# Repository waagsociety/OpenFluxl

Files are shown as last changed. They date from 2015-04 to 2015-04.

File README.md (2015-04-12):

# OpenFluxl
Open Source Digital Microfluidic Device

> This project is currently under development at Waag Society's Open Wetlab

# OpenFluxl v.0.1 Release Notes

# Circuit

The OpenFluxl Device needs to apply a voltage of approx. 300V to individual fluxls. In order to generate this potential from 12V a Boost Converter circuit is necessary.

The circuit is based on: http://reibot.org/2011/08/07/intro-to-boost-converter/

A TVS diode is added in the circuit over the main capacitor as an additional safety measure.

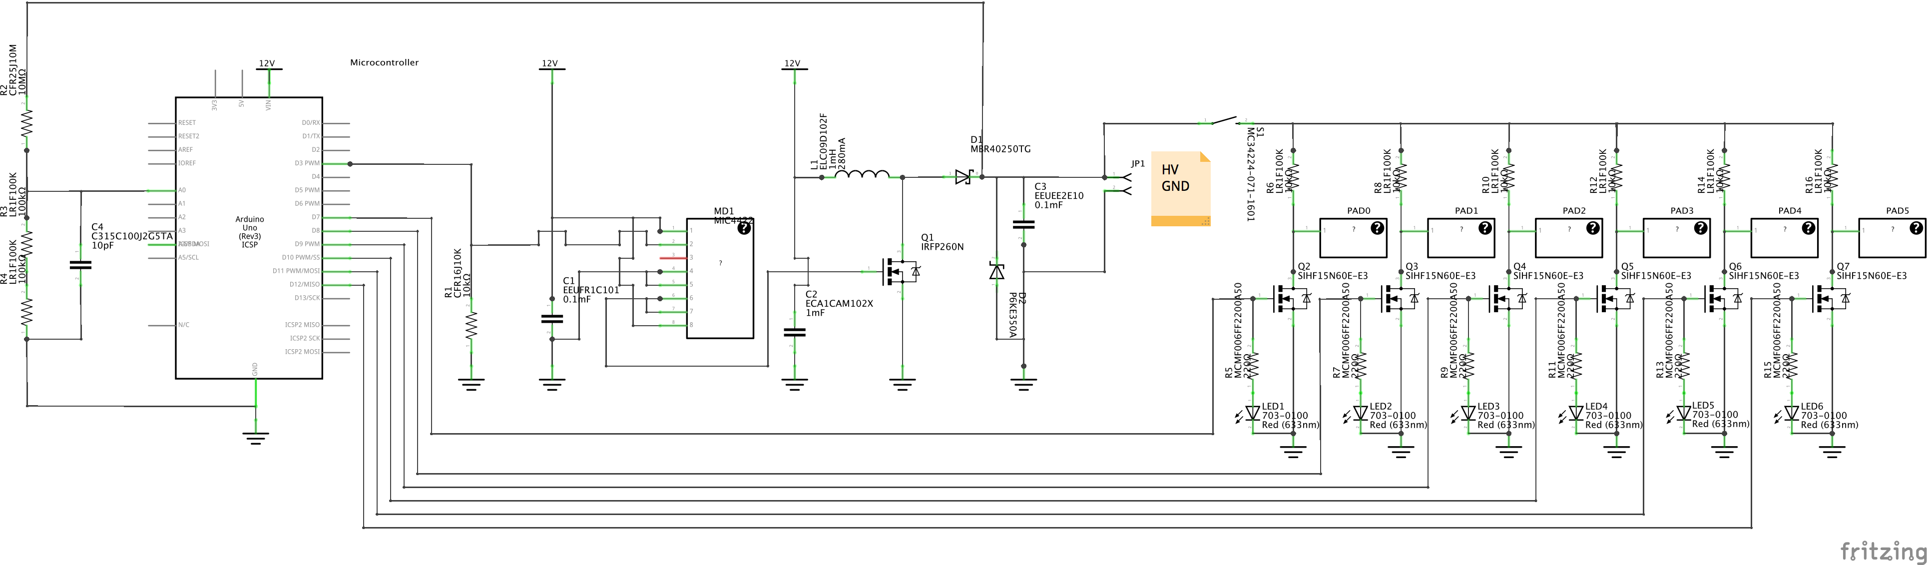
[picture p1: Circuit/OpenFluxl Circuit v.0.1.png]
Circuit Scheme


# Arduino Code

The Arduino code is based on: http://reibot.org/2011/08/07/intro-to-boost-converter/

# PCB

For initial testing the PCB of GuadiLabs OpenDrop is used: http://www.gaudi.ch/GaudiLabs/?attachment_id=440

# Components

Only through hole components have been used for breadboard prototyping.

The 1000V USB prototector is optional, for the brave.

# Pictures
Boost Converter:
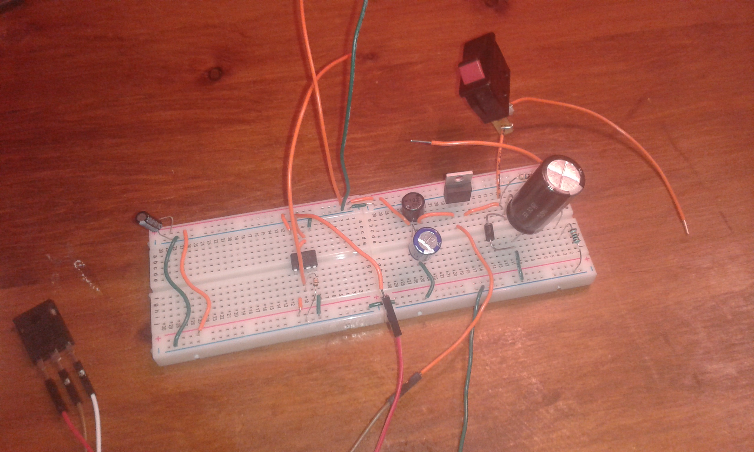
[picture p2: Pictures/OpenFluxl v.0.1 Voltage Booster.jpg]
Boost Converter


Fluxl Controller:
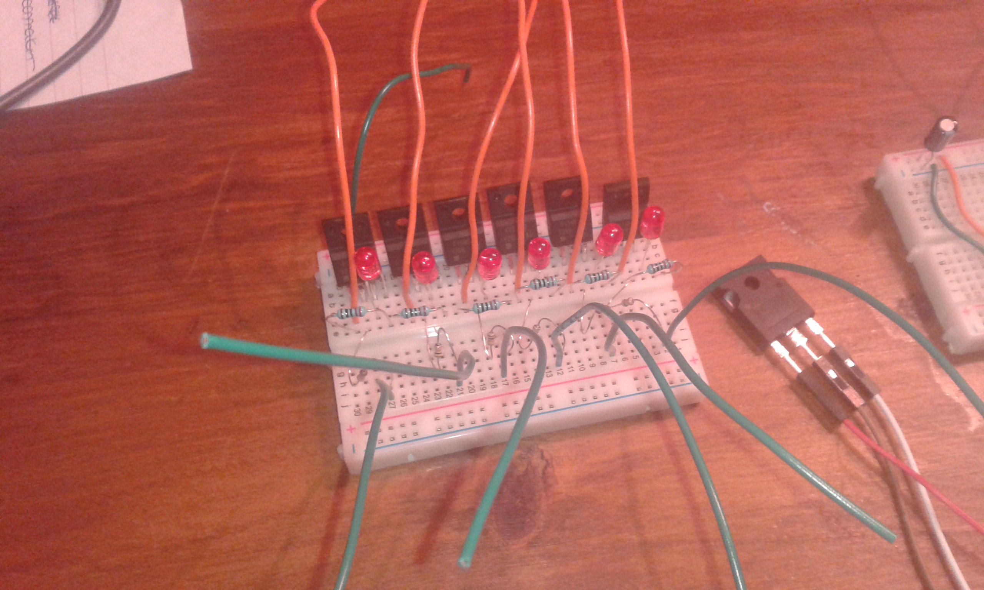
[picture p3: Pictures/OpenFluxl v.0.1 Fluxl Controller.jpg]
Fluxl Controller


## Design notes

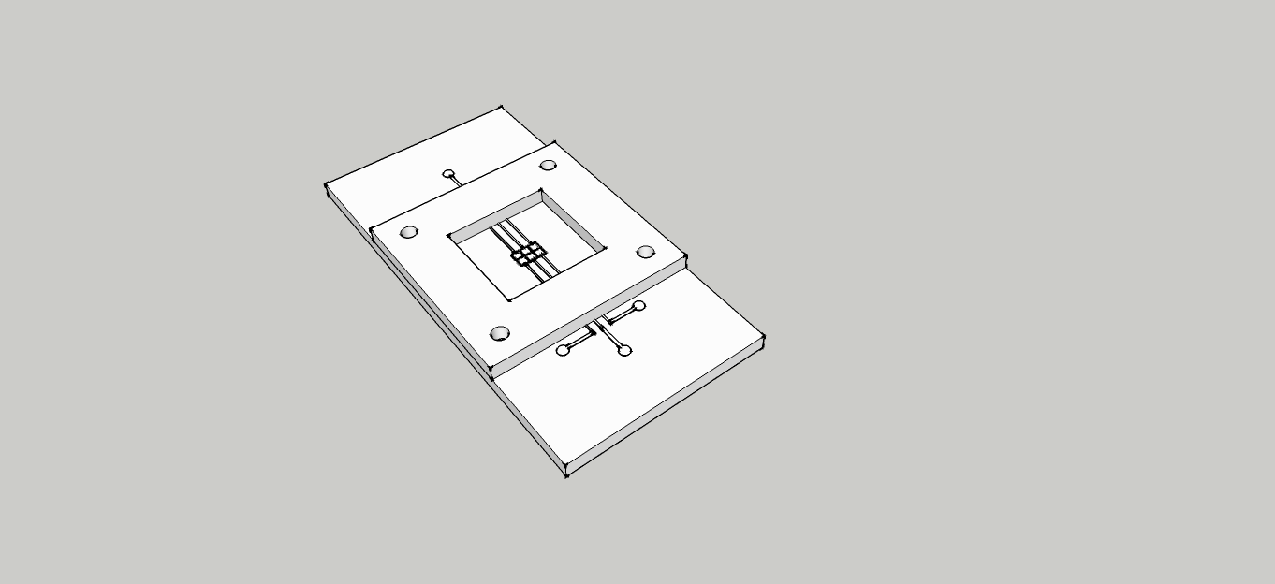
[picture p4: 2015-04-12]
PCB/OpenFluxl Device v.0.1.png

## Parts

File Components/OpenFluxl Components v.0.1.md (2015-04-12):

#OpenFluxl Components v.0.1

| No  | Amount | Description | Supplier | Cost |
| --- |:---:| --- | --- | ---- |
| 1 | 1 | IRFP260NPBF N-channel MOSFET | [Farnell](http://nl.farnell.com/international-rectifier/irfp260npbf/mosfet-n-200v-49a-to-247ac/dp/8649294) | 4.11 |
|2|1|MIC4422YN MOSFET Driver|[Farnell](http://nl.farnell.com/micrel-semiconductor/mic4422yn/ic-mosfet-driver-non-inverting/dp/1556746)|2.61|
|3|1|MBR40250TG Schottky Diode|[Farnell](http://nl.farnell.com/on-semiconductor/mbr40250tg/diode-schottky-40a-250v-to-220/dp/1431066)|2.17|
|4|1|EEUEE2E101 100 uF 250V Capacitor|[Farnell](http://nl.farnell.com/panasonic-electronic-components/eeuee2e101/cap-alu-elec-100uf-250v-rad/dp/1673472)|1.61|
|5|1|ELC09D102F 1000 uH Choke|[Farnell](http://nl.farnell.com/panasonic-electronic-components/elc09d102f/choke-1000uh-0-28a--10/dp/8094772)|0.40|
|6|1|ECA1CAM102X 1000 uF 16V Capacitor|[Farnell](http://nl.farnell.com/panasonic-electronic-components/eca1cam102x/cap-alu-elec-1000uf-16v-rad/dp/8767165)|0.24|
|7|1|EEUFR1C101 100 uF 16V Capacitor|[Farnell](http://nl.farnell.com/panasonic-electronic-components/eeufr1c101/cap-alu-elec-100uf-16v-rad/dp/1907228)|0.11|
|8|1|C315C100J2G5TA 10 pF 200V Capacitor|[Farnell](http://nl.farnell.com/kemet/c315c100j2g5ta/cap-mlcc-c0g-10pf-200v-rad/dp/2429324)|0.20|
|9|7|CFR16J10K 10K resistor|[Farnell](http://nl.farnell.com/te-connectivity/cfr16j10k/resistor-carbon-10k-0-25w-5/dp/2329474)|0.14|
|10|2|LR1F100K 100K resistor|[Farnell](http://nl.farnell.com/te-connectivity/lr1f100k/resistor-metal-100k-0-6w-1/dp/2329987)|0.08|
|11|1|CFR25J10M 10M resistor|[Farnell](http://nl.farnell.com/te-connectivity/cfr25j10m/resistor-carbon-10m-0-33w-5/dp/2329611)|0.02|
|12|1|MC34224-071-1601 switch|[Farnell](http://nl.farnell.com/multicomp/mc34224-071-1601/switch-spdt-20a-250vac-blk-red/dp/1454382)|0.77|
|13|6|MCMF006FF2200A50 220 resistor|[Farnell](http://nl.farnell.com/multicomp/mcmf006ff2200a50/resistor-metal-film-220-ohm-1/dp/2401736)|0.09|
|14|6|703-0100 Red 5mm LED|[Farnell](http://nl.farnell.com/multicomp/703-0100/led-5mm-red-400mcd-643nm/dp/2112111)|1.31|
|15|6|SIHF15N60E-E3 N-channel MOSFET|[Farnell](http://nl.farnell.com/vishay-siliconix/sihf15n60e-e3/mosfet-n-ch-600v-15a-to220fp/dp/2283636)|11.50|
|16|1|P6KE350A 330V TVS Diode|[Farnell](http://nl.farnell.com/fairchild-semiconductor/p6ke350a/diode-tvs-600w-smd-do-15/dp/1470976)|0.13|
|17|1|A000066 Arduino Uno|[Farnell](http://nl.farnell.com/arduino/a000066/atmega328-arduino-uno-eval-board/dp/2075382)|22.15|
|18|1|1195114 1000V isolator voor DEV AU USB-ISO OLX|[Conrad](https://www.conrad.nl/nl/developmentboard-olimex-usb-iso-1195114.html)|57.99|

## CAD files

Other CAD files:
PCB/OpenFluxl Device v.0.1.skp

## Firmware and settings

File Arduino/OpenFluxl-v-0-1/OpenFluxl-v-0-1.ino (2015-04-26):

/* 
OpenFluxl Arduino Code

PID Controller based on:
http://reibot.org/2011/08/07/intro-to-boost-converter/

Check wiring:
- Feedback connected to Analog 1.s
- Pwm pin is on digital 3

*/

#include <PID_v1.h>

// Version
String FluxlVersion = "v.0.1";

// PID variables
double Setpoint, Input, Output;

// Initiate PID
PID myPID(&Input, &Output, &Setpoint, .8, .1, .01, DIRECT);

// Vars
int targetVoltage = 100;
int numFluxls = 6;
String buffer;

// Pins
int DriverPin = 3;
int FluxlPins[] = {7,8,9,10,11,12};

void setup(){
  
  // Open Serial Connection
  Serial.begin(115200);

  // Set Pin Modes
  for(int i=0;i<numFluxls;i++) {
    pinMode(FluxlPins[i],OUTPUT);
  }
  pinMode(DriverPin, OUTPUT); // Mosfet Driver (OCR2A)
  
  // Change PWM frequency
  pwmSetup(); // set pwm to 31 KHz
  
  // Set PID
  myPID.SetMode(AUTOMATIC);
  myPID.SetOutputLimits(0,255);
  
  // PID update speed in ms
  myPID.SetSampleTime(10); 
  
  // Print message
  Serial.print("OpenFluxl ");
  Serial.println(FluxlVersion);
}

void loop(){

  PidUpdate();

  // Serial Commands
  while (Serial.available()>0) {
    char c = (char)Serial.read();
    if (c == '\n') {
      if(buffer.startsWith("id")) {
        Serial.print("id:OpenFluxl "); // device identifier
        Serial.println(FluxlVersion); 
      } else if (buffer.startsWith("vol")) {
        // Change target voltage
        targetVoltage = buffer.substring(3).toInt();
        
        // Sanity check
        if(targetVoltage < 0) targetVoltage = 0;
        else if(targetVoltage > 300) targetVoltage = 300;
        else targetVoltage = 0;
        
        // Report through serial
        Serial.print(F("Setting target voltage to: "));
        Serial.print(targetVoltage);
        Serial.println(F(" V"));
      } else if (buffer.startsWith("fluxl")) {
        // move droplet to new fluxl
        int tmpInt = buffer.substring(5).toInt();
        
        // Sanity check
        if(tmpInt < 0) tmpInt = 0;
        else if(tmpInt > 5) tmpInt = 5;
        else tmpInt = 0; 
        
        moveDrop(tmpInt);
      }
      else {
        Serial.println(F("Unknown cmd."));
      }
      buffer="";
    } else buffer+=c;
  }  
  
  delay(10);
}

void PidUpdate() {

  // Voltage devider to measure voltage
  
  double R2 = 200000;
  double R1 = 10000000;
  
  double voltage = (analogRead(A1) / 1023.)*4.9*(R2+R1)/R2;
  
  Input = voltage;
  Setpoint = targetVoltage;
  myPID.Compute();

  if(voltage > targetVoltage + 10) { 
    analogWrite(DriverPin,0); //OCR2A = 0;
  } else if(voltage <= targetVoltage) {
    analogWrite(DriverPin,Output); //OCR2A = Output;
  }
  
  Serial.print("Voltage: ");
  Serial.print(voltage);
  
  Serial.print("\tADC voltage: ");
  Serial.print((analogRead(A1)/1023.)*4.9);
  
  Serial.print("\tduty: ");
  Serial.println((int)Output);
  
}

void moveDrop(int TargetFluxl) {
  // Open the circuit through the target Fluxl
  for(int i=0;i<numFluxls;i++) {
    if(i==TargetFluxl) {
      digitalWrite(FluxlPins[i],HIGH);
      
      // Report through serial
      Serial.print(F("Moving droplet to Fluxl: "));
      Serial.println(i);      
    }
    else {
      digitalWrite(FluxlPins[i],LOW);
    }
  }
}

void pwmSetup(){
  
/* Derived from: http://letsmakerobots.com/content/changing-pwm-frequencies-arduino-controllers */
//---------------------------------------------- Set PWM frequency for D5 & D6 -------------------------------
//TCCR0B = TCCR0B & B11111000 | B00000001;    // set timer 0 divisor to     1 for PWM frequency of 62500.00 Hz
//TCCR0B = TCCR0B & B11111000 | B00000010;    // set timer 0 divisor to     8 for PWM frequency of  7812.50 Hz
TCCR0B = TCCR0B & B11111000 | B00000011;    // set timer 0 divisor to    64 for PWM frequency of   976.56 Hz
//TCCR0B = TCCR0B & B11111000 | B00000100;    // set timer 0 divisor to   256 for PWM frequency of   244.14 Hz
//TCCR0B = TCCR0B & B11111000 | B00000101;    // set timer 0 divisor to  1024 for PWM frequency of    61.04 Hz

//---------------------------------------------- Set PWM frequency for D9 & D10 ------------------------------
//TCCR1B = TCCR1B & B11111000 | B00000001;    // set timer 1 divisor to     1 for PWM frequency of 31372.55 Hz
//TCCR1B = TCCR1B & B11111000 | B00000010;    // set timer 1 divisor to     8 for PWM frequency of  3921.16 Hz
TCCR1B = TCCR1B & B11111000 | B00000011;    // set timer 1 divisor to    64 for PWM frequency of   490.20 Hz
//TCCR1B = TCCR1B & B11111000 | B00000100;    // set timer 1 divisor to   256 for PWM frequency of   122.55 Hz
//TCCR1B = TCCR1B & B11111000 | B00000101;    // set timer 1 divisor to  1024 for PWM frequency of    30.64 Hz

//---------------------------------------------- Set PWM frequency for D3 & D11 ------------------------------
TCCR2B = TCCR2B & B11111000 | B00000001;    // set timer 2 divisor to     1 for PWM frequency of 31372.55 Hz
//TCCR2B = TCCR2B & B11111000 | B00000010;    // set timer 2 divisor to     8 for PWM frequency of  3921.16 Hz
//TCCR2B = TCCR2B & B11111000 | B00000011;    // set timer 2 divisor to    32 for PWM frequency of   980.39 Hz
//TCCR2B = TCCR2B & B11111000 | B00000100;    // set timer 2 divisor to    64 for PWM frequency of   490.20 Hz
//TCCR2B = TCCR2B & B11111000 | B00000101;    // set timer 2 divisor to   128 for PWM frequency of   245.10 Hz
//TCCR2B = TCCR2B & B11111000 | B00000110;    // set timer 2 divisor to   256 for PWM frequency of   122.55 Hz
//TCCR2B = TCCR2B & B11111000 | B00000111;    // set timer 2 divisor to  1024 for PWM frequency of    30.64 Hz

  analogWrite(11,0);
  analogWrite(DriverPin,0);
  
}

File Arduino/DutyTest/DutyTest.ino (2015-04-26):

/*
OpenFluxl Arduino Test Code
- Without Feedback or PID Control
*/

int DriverPin = 3;

void setup() {
  // put your setup code here, to run once:

  // Set PWM frequency for D3 & D11 
  TCCR2B = TCCR2B & B11111000 | B00000001;    // set timer 2 divisor to     1 for PWM frequency of 31372.55 Hz

  // Start with 0% duty cycle
  analogWrite(DriverPin,0);
  analogWrite(11,0);

}

void loop() {
  // put your main code here, to run repeatedly: 
  
  // 25% Duty Cycle: 64
  // 50% Duty Cycle: 127
  // 75% Duty Cycle: 191
  // 100% Duty Cycle: 255
  
  analogWrite(DriverPin,127);
  
}

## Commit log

2015-04-12 v.0.1 first push
    [OpenFluxl Circuit v.0.1.fzz, OpenFluxl Device v.0.1.skp]
2015-04-26 Change DriverPin to 3
2015-04-26 Fix array size error
    [OpenFluxl-v-0-1.ino]
2015-04-26 fix fluxl command interpretation
    [OpenFluxl-v-0-1.ino]
